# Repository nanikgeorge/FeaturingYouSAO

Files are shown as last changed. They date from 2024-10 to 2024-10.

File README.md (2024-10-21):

# Featuring You!
This is an SAO I designed to share at Hackaday Supercon 2024.

Supercon badges are awesome! But for some reason they don't always have a spot to put your name, this is my solution. An SAO that looks like one of those big red flashing arrows - featuring you!

What is an SAO? Here's a Hackaday article about that: [https://hackaday.com/2019/03/20/introducing-the-shitty-add-on-v1-69bis-standard/](https://hackaday.com/2019/03/20/introducing-the-shitty-add-on-v1-69bis-standard/)

Interested in attending Hackaday Supercon 2024? Last year was a lot of fun - this year I'm speaking so make sure to check it out: [https://hackaday.io/superconference/](https://hackaday.io/superconference/)

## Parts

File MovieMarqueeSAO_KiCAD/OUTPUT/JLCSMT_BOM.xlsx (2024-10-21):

Comment | Designator | Footprint | JLCPCB Part #（optional）
header | J1 | PinHeader_2x02_P2.54mm_Vertical
White LED | D32,D31,D30,D29,D28,D27,D26,D25,D24,D23,D22,D21,D20,D19,D18,D17,D16,D15,D14,D13,D12,D11,D10,D9,D8,D7,D6,D5,D4,D3,D2,D1 | D_0603_1608Metric | C2290
5.6K Resistor | R4,R1 | R_0603_1608Metric | C23189
150K Resistor | R3,R2 | R_0603_1608Metric | C22807
MMBT3904 | Q4,Q2,Q1,Q3 | SOT-23 | C20526
10u Capacitor | C2,C1 | C_0603_1608Metric

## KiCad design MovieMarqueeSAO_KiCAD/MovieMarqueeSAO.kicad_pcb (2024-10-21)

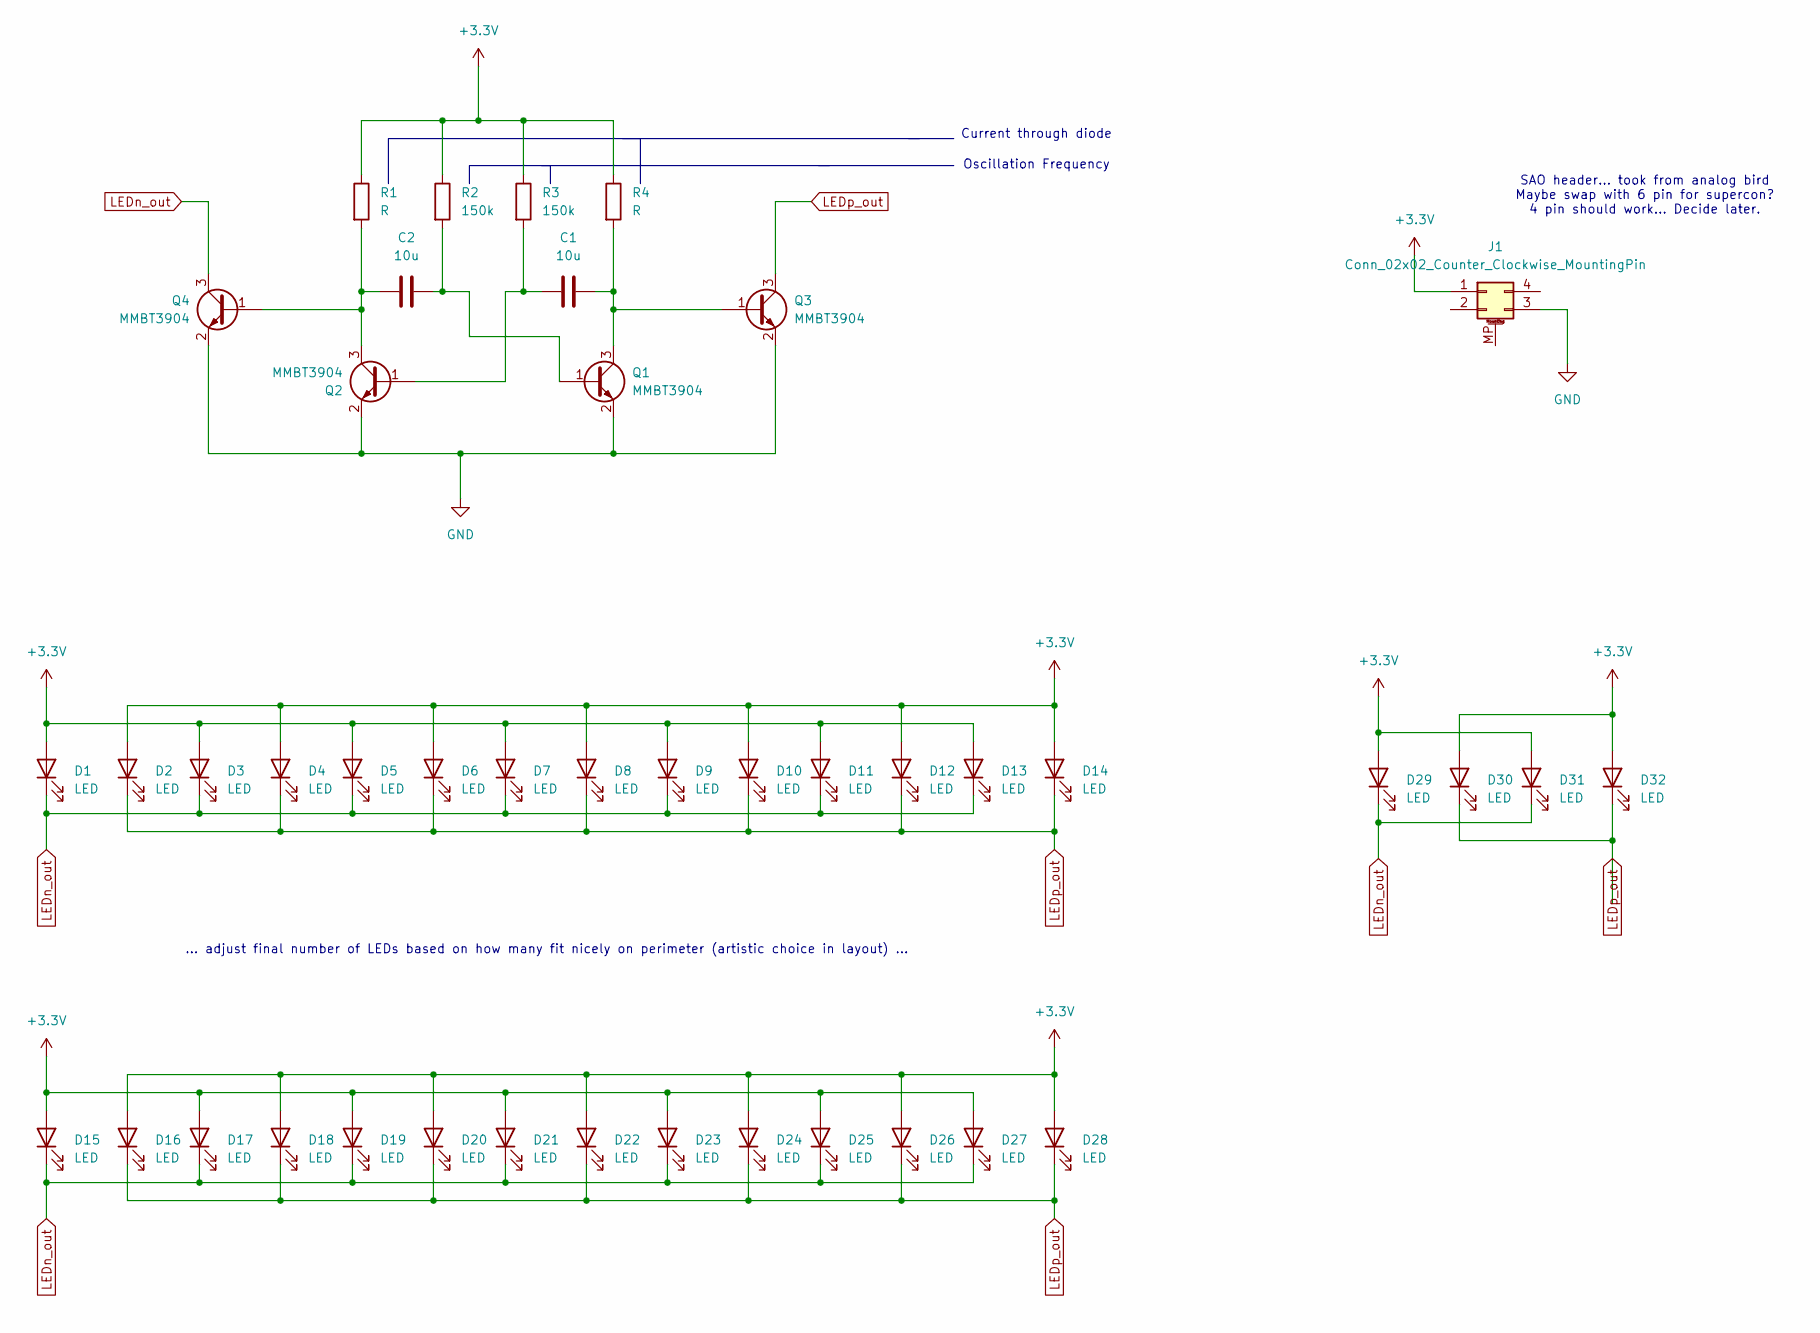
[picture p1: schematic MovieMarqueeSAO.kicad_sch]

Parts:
C1, C2: 10u; C_0603_1608Metric
D1, D2, D3, D4, D5, D6, D7, D8, D9, D10, D11, D12, D13, D14, D15, D16, D17, D18, D19, D20, D21, D22, D23, D24, D25, D26, D27, D28, D29, D30, D31, D32: LED; D_0603_1608Metric
J1: Conn_02x02_Counter_Clockwise_MountingPin; PinHeader_2x02_P2.54mm_Vertical
Q1, Q2, Q3, Q4: MMBT3904; SOT-23
R1, R4: R; R_0603_1608Metric
R2, R3: 150k; R_0603_1608Metric

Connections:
+3.3V: D1.2 (A), D2.2 (A), D3.2 (A), D4.2 (A), D5.2 (A), D6.2 (A), D7.2 (A), D8.2 (A), D9.2 (A), D10.2 (A), D11.2 (A), D12.2 (A), D13.2 (A), D14.2 (A), D15.2 (A), D16.2 (A), D17.2 (A), D18.2 (A), D19.2 (A), D20.2 (A), D21.2 (A), D22.2 (A), D23.2 (A), D24.2 (A), D25.2 (A), D26.2 (A), D27.2 (A), D28.2 (A), D29.2 (A), D30.2 (A), D31.2 (A), D32.2 (A), J1.1, R1.1, R2.1, R3.1, R4.1
GND: J1.3, Q1.2 (E), Q2.2 (E), Q3.2 (E), Q4.2 (E)
LEDn_out: D1.1 (K), D3.1 (K), D5.1 (K), D7.1 (K), D9.1 (K), D11.1 (K), D13.1 (K), D15.1 (K), D17.1 (K), D19.1 (K), D21.1 (K), D23.1 (K), D25.1 (K), D27.1 (K), D29.1 (K), D31.1 (K), Q4.3 (C)
LEDp_out: D2.1 (K), D4.1 (K), D6.1 (K), D8.1 (K), D10.1 (K), D12.1 (K), D14.1 (K), D16.1 (K), D18.1 (K), D20.1 (K), D22.1 (K), D24.1 (K), D26.1 (K), D28.1 (K), D30.1 (K), D32.1 (K), Q3.3 (C)
unnamed: C2.2, Q1.1 (B), R2.2
unnamed: C1.2, Q1.3 (C), Q3.1 (B), R4.2
unnamed: C1.1, Q2.1 (B), R3.2
unnamed: C2.1, Q2.3 (C), Q4.1 (B), R1.2

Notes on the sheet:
SAO header... took from analog bird Maybe swap with 6 pin for supercon? 4 pin should work... Decide later.
Oscillation Frequency
Current through diode
... adjust final number of LEDs based on how many fit nicely on perimeter (artistic choice in layout) ...

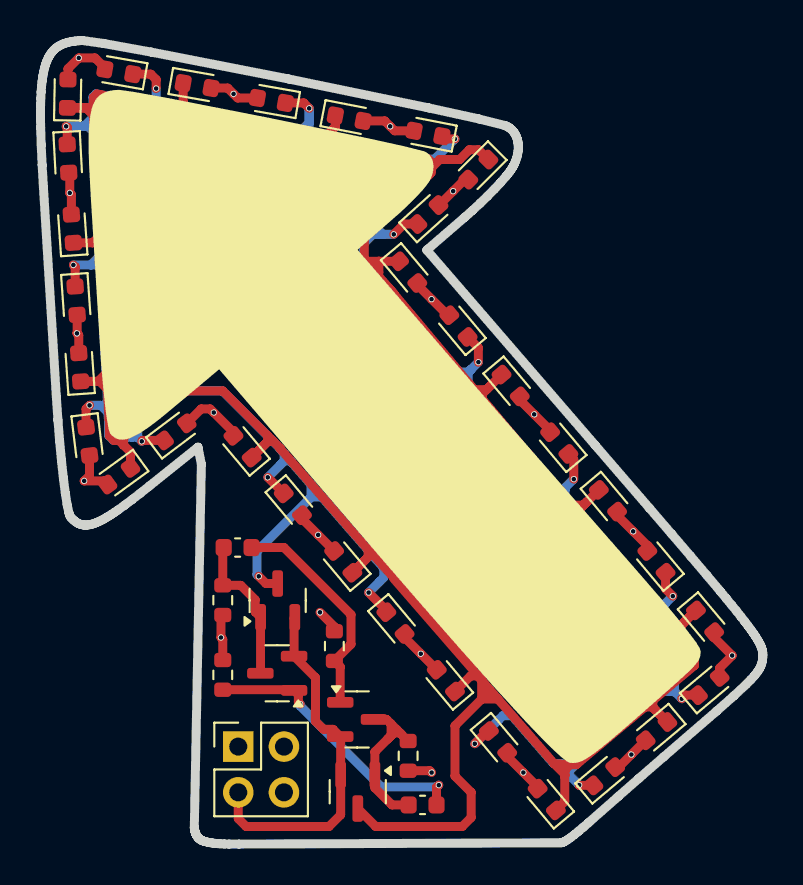
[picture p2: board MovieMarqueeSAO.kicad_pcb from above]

Board: 2 copper layers, 40.1 x 44.6 mm, 43 parts (0 on the bottom side), 8 nets.
